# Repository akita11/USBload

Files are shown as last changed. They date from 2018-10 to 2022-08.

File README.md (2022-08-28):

# USBload
Dummy USB load

usbload

## これは何？
マイコンボードやLEDなどをモバイルバッテリーで駆動させるとき、急に電源が切れてしまうことはありませんか？
大抵のモバイルバッテリーは消費電流が弱い時にスリープするようになっています。

本モジュールをモバイルバッテリーに取り付けることで、定期的に負荷電流を流すことで、モバイルバッテリーをスリープさせないようにすることができます。

本モジュールは間欠で電流を流すことで、モバイルバッテリーの動作時間により影響を与えないようにしました。
また、端子を結線することで、消費電流値と電流の間欠期間を設定できます。
それにより、使用するモバイルバッテリーの挙動に合わせ、動作を調整することができます。

## USBloadとUSBload2の違い
モバイルバッテリーによってオス側が差し込めないものがあるとのご意見を戴き、USBload2はAタイプのオスコネクタをつけました。

※USBload2.1では使用するマイコンがSTC8G1K08に変更になっていますが、使い方は変更ありません。

usbload2

## 使い方
モバイルバッテリーに本モジュールのオス側を差し込み、メスコネクタに給電用USBケーブルを差し込むだけです。

※使用するモバイルバッテリーにあわせて、以下の「設定」を行う必要があります。

## 設定

### 電流間欠期間の設定方法

本モジュールを接続しない状態で、モバイルバッテリーをONにし、その後、自動的にスリープに入る（給電が止まる）までの時間を計測します。その時間に応じて、以下のとおり間欠期間を設定します。

間欠期間は、上記画像の赤色のA,Bパターンをショートすることで設定できます。

|A|B|間欠期間|補足|
|----|----|----|----|
|オープン|オープン|約24秒|30秒でスリープするモバイルバッテリー向け|
|ショート|オープン|約16秒|20秒でスリープするモバイルバッテリー向け|
|オープン|ショート|約12秒|15秒でスリープするモバイルバッテリー向け|
|ショート|ショート|約8秒|10秒でスリープするモバイルバッテリー向け|

### 消費電流値の設定方法
デフォルトで100mA流れるようになっており、上記画像の青色のパターンを1つショートするごとに電流値が100mA増えます。
多くのモバイルバッテリーは100mAのままでスリープを回避できるようですが、より多くの電流が必要なものもありますので、100mAのままではスリープを回避できない場合は、順に流す電流を増やしてください、

## その他
サイズ(USBload) : 18×12×10.5mm
サイズ(USBload2) : 35.6×17×11mm
モジュールの消費電流値 : 100mA～400mA  
モジュールの電流増減インターバル : 約10～30秒  

## （参考：自作する方向け）

USBload2.1（使用マイコン: STC8G1K08）のプログラムの書き込み方法はUSBload21_pgm.pdfを参照してください。

## 終わりに

USBloadの改良点がありましたら、ぜひIsuuesに書いてください。
こんな作品に作ったよ！という方は [#USBload](https://twitter.com/search?q=%23USBload&src=typed_query) を付けてSNSなどで公開してくださると嬉しいです。

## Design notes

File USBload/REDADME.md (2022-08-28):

# USBload/USBload2のプログラム書き込み方法

USBload/USBload2（使用マイコン：ATtiny10）の書き込みは[こちら](https://make.kosakalab.com/make/electronic-work/arduino-ide-dev/)を参照してください。

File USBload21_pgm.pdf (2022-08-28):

USBload2.1 の書き込み⽅法
2022/6/13 akita11

準備するもの
・ USB-シリアル変換器(FTDI-Basic 等。IO レベルが 5V のもの)
・ WindowsPC
・ 書き込みソフト：http://www.stcmcudata.com/ から「STC-ISP 软件 V6.89E 版」をダ ウンロードして展開
・ 書き込みケーブル（⾃作）：USBload2s と USB-シリアル変換器を以下のように接続す る。USB ケーブルを切断して A（平たい⽅）側から伸びるケーブルを、USB-シリアル 変換器につなぐピンヘッダにつなぐのが楽か？
Ø USB-A の p1(VDD)----USB-シリアル変換器の VDD(+5V)
Ø USB-A の p2(D-)---- USB-シリアル変換器の RXD
Ø USB-A の p3(D+)---- USB-シリアル変換器の TXD
Ø USB-A の p4(GND)---- USB-シリアル変換器の GND

書き込みソフト(STC-ISP)の初期設定
書き込みソフト STC-ISP を起動し、以下の 2 箇所を設定
・ MCU Type：”STC8G1K08A-8PIN”を選択
・ Scan Port：USB-シリアル変換器の COM ポート（たぶん⾃動で出てくる） ・ Open Code File：こちらの”USBlaod2S.bin”を指定 https://www.dropbox.com/s/422zqcihnlwcrv4/USBload2S.bin?dl=0
・ “H/W Option”内の下の⽅にある”Add a reset code in front of ID”をチェック

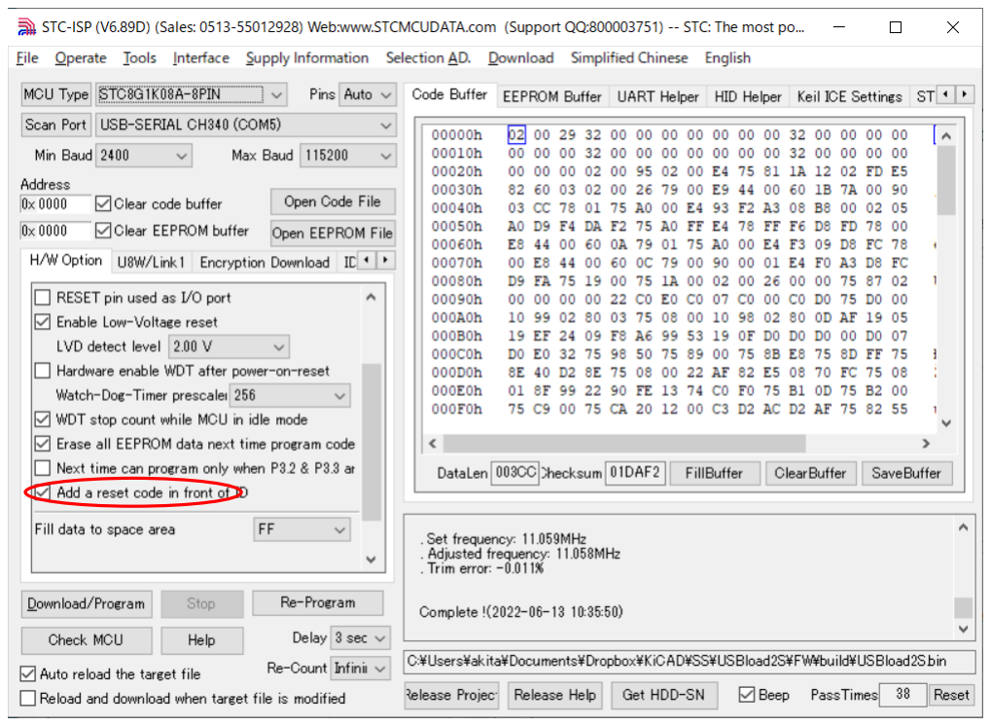
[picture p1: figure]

書き込み
1. STC-ISP で”Download/Program”ボタンを押す
2. USBload2S を書き込みケーブル（⾃作）に接続
3. 書き込みが始まり、すぐに終了するはず（STC-ISP の右下のエリア内に”Complete!”と 出ていれば OK

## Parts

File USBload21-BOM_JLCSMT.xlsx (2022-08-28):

Comment | Designator | Footprint | JLCPCB Part #（optional）
0.1uF | C1 | C0603 | C14663
USB-A recepctacle/TH | J3 |  | C2345
nMOS | Q1 | SOT23 | C20917
10k | R1 | R0603 | C25804
1.1k | R2 | R0603 | C22764
51 | R3,R4,R5,R6 | R0805 | C17732
STC8G1K08 | U1 | DFN8 | C915664

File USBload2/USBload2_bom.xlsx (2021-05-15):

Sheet: PCB Specification
Your PCB Specification
PCB Quantity | 100pcs
Layer | 2layer
PCB Thickness | 1.6mm
Dimensions | 20.6mm x 17.1mm
Castellated Hole | No
PCB Color | Black
Surface Finish | HASL Lead Free
Copper Weight | 1oz
Text Color | White
Different Design | 1
Please find more PCB information on our on-line PCB ordering Page
https://www.elecrow.com/pcb-manufacturing.html

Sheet: BOM
USBload2
# | Reference | QTY | Value | Package | Manufacturer Part number | Description | SMD | THT | Original | Elecrow PN | Note
1 | R1 | 1 | 10k | R0603 | P10KGCT-ND | Resistor | 2 |  | N
2 | R2-R4 | 4 | 51 | R0805 | RMCF0805JT51R0TR-ND | Resistor | 8 |  | N
2 | Q1 | 1 | IRLML6344 | SOT23-3 | IRLML6344TRPBFTR-ND | nMOS | 3 |  | Y
3 | U1 | 1 | ATTINY10 | SOT23-6 | ATTINY10-TSHRCT-ND | MCU | 6 |  | Y
4 | J2 | 1 |  |  | 102-3996-ND | USB connector |  | 6 | N
4 | J3 | 1 |  |  | 380-1412-ND | USB connector |  | 6 | N
5 | C1 | 1 | 0.1uF | C0603 |  | Capacitor | 2 |  | N
 |  |  |  |  |  | total： | 21 | 12
 | Declare：
 | 1、If the component should be original like Digi-key or Mouser，the component must have complete Manufacture part number

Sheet: Position File
Designator | Footprint | Center-X(mm) | Center-Y(mm) | Layer | Rotation
C1 | C_0603_1608Metric | 6.35 | 1.02 | BottomLayer | 180
Q1 | SOT-23 | 2.03 | 4.83 | BottomLayer | 0
R1 | R_0603_1608Metric | 2.03 | 2.29 | BottomLayer | 180
R2 | R_0805_2012Metric | 4.83 | 9.91 | BottomLayer | 270
R3 | R_0805_2012Metric | 12.19 | 9.91 | BottomLayer | 270
R4 | R_0805_2012Metric | 9.91 | 9.91 | BottomLayer | 270
R5 | R_0805_2012Metric | 7.87 | 9.91 | BottomLayer | 270
U1 | SOT-23-6 | 6.35 | 3.56 | BottomLayer | 180
J2 | USB Plug | 8.58 | 15.24 | TopLayer | 0
J3 | USB Recpt | 5.08 | 12.70 | TopLayer | 0

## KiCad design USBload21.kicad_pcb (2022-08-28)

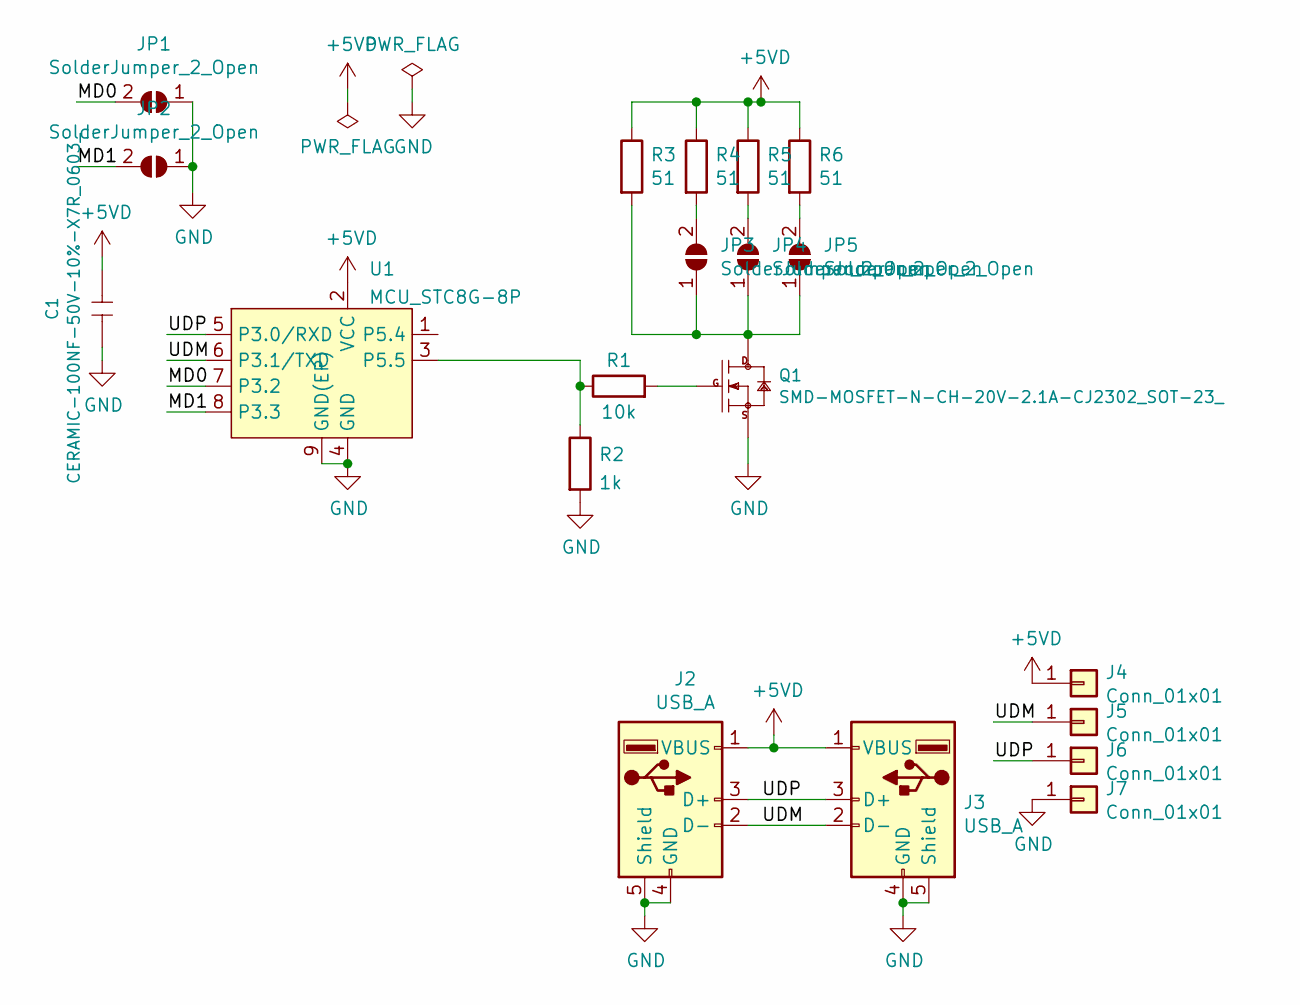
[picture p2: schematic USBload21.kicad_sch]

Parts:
C1: CERAMIC-100NF-50V-10%-X7R_0603_; C_0603_1608Metric; MPN CC0603KRX7R9BB104
J2: USB_A; USB-A_plug
J3: USB_A; USB_A_Stewart_SS-52100-001_Horizontal
J4, J5, J6, J7: Conn_01x01; Pad_SMD1.6mm
JP1, JP2, JP3, JP4, JP5: SolderJumper_2_Open; SolderJumper-2_P1.3mm_Open_RoundedPad1.0x1.5mm
Q1: SMD-MOSFET-N-CH-20V-2.1A-CJ2302_SOT-23_; SOT-23; MPN CJ2302
R1: 10k; R_0603_1608Metric
R2: 1k; R_0603_1608Metric
R3, R4, R5, R6: 51; R_0805_2012Metric
U1: MCU_STC8G-8P; DFN-8-1EP_3x3mm_P0.5mm_EP1.66x2.38mm

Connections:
+5VD: C1.2, J2.1 (VBUS), J3.1 (VBUS), J4.1, R3.1, R4.1, R5.1, R6.1, U1.2 (VCC)
/MD0: JP1.2 (B), U1.7 (P3.2)
/MD1: JP2.2 (B), U1.8 (P3.3)
/UDM: J2.2 (D-), J3.2 (D-), J5.1, U1.6 (P3.1/TXD)
/UDP: J2.3 (D+), J3.3 (D+), J6.1, U1.5 (P3.0/RXD)
GND: C1.1, J2.4 (GND), J2.5 (Shield), J3.4 (GND), J3.5 (Shield), J7.1, JP1.1 (A), JP2.1 (A), Q1.2 (S), R2.2, U1.4 (GND), U1.9 (GND(EP))
unnamed: JP3.1 (A), JP4.1 (A), JP5.1 (A), Q1.3 (D), R3.2
unnamed: JP3.2 (B), R4.2
unnamed: JP4.2 (B), R5.2
unnamed: JP5.2 (B), R6.2
unnamed: Q1.1 (G), R1.2
unnamed: R1.1, R2.1, U1.3 (P5.5)

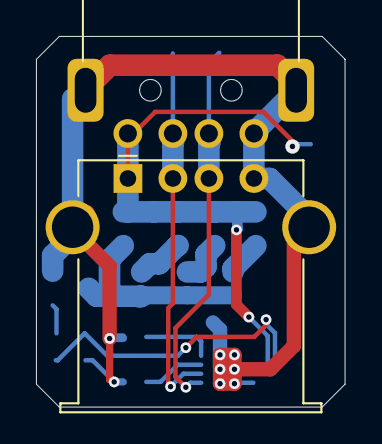
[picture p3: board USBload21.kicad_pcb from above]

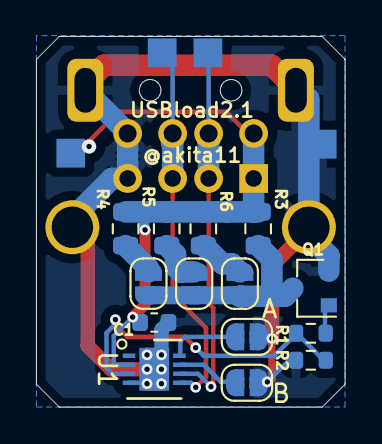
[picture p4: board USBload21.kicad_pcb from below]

Board: 2 copper layers, 17.1 x 20.6 mm, 20 parts (18 on the bottom side), 12 nets.

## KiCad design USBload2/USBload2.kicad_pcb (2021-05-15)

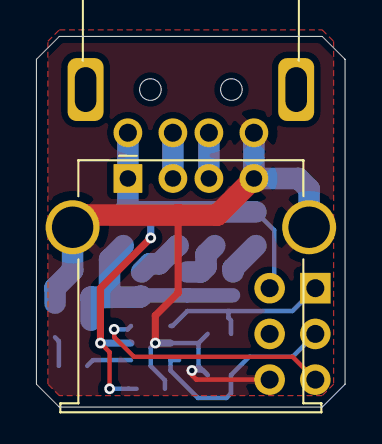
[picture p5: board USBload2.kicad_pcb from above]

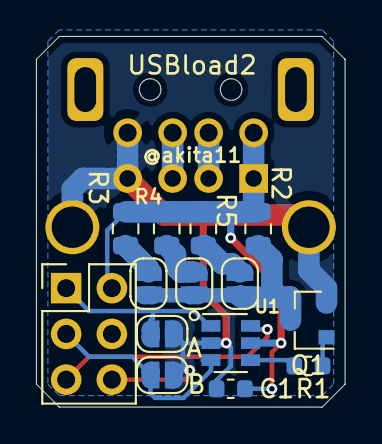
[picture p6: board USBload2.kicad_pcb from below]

Board: 2 copper layers, 17.1 x 20.6 mm, 16 parts (14 on the bottom side), 13 nets.

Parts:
C1: CERAMIC-100NF-50V-10%-X7R_0603_; C_0603_1608Metric
J1: AVR-ISP-6; PinHeader_2x03_P2.54mm_Vertical
J2: USB_A; USB-A_plug
J3: USB_A; USB_A_Stewart_SS-52100-001_Horizontal
JP1, JP2, JP3, JP4, JP5: SolderJumper_2_Open; SolderJumper-2_P1.3mm_Open_RoundedPad1.0x1.5mm
Q1: SMD-MOSFET-N-CH-20V-2.1A-CJ2302_SOT-23_; SOT-23
R1: SMD-RES-10K-1%-1_10W_0603_; R_0603_1608Metric
R2, R3, R4, R5: 51; R_0805_2012Metric
U1: ATtiny10-TS; SOT-23-6

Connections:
+5VD: C1.2, J1.2, J2.1, J3.1, R2.1, R3.1, R4.1, R5.1, U1.5
/PB0: J1.1, JP1.2, U1.1
/PB1: J1.3, JP2.2, U1.3
/PB3: J1.5, U1.6
GND: C1.1, J1.6, J2.4, J3.4, J3.5, JP1.1, JP2.1, Q1.2, U1.2
unnamed: J2.2, J3.2
unnamed: J2.3, J3.3
unnamed: JP3.1, JP4.1, JP5.1, Q1.3, R2.2
unnamed: JP3.2, R3.2
unnamed: JP4.2, R4.2
unnamed: JP5.2, R5.2
unnamed: Q1.1, R1.2
unnamed: R1.1, U1.4

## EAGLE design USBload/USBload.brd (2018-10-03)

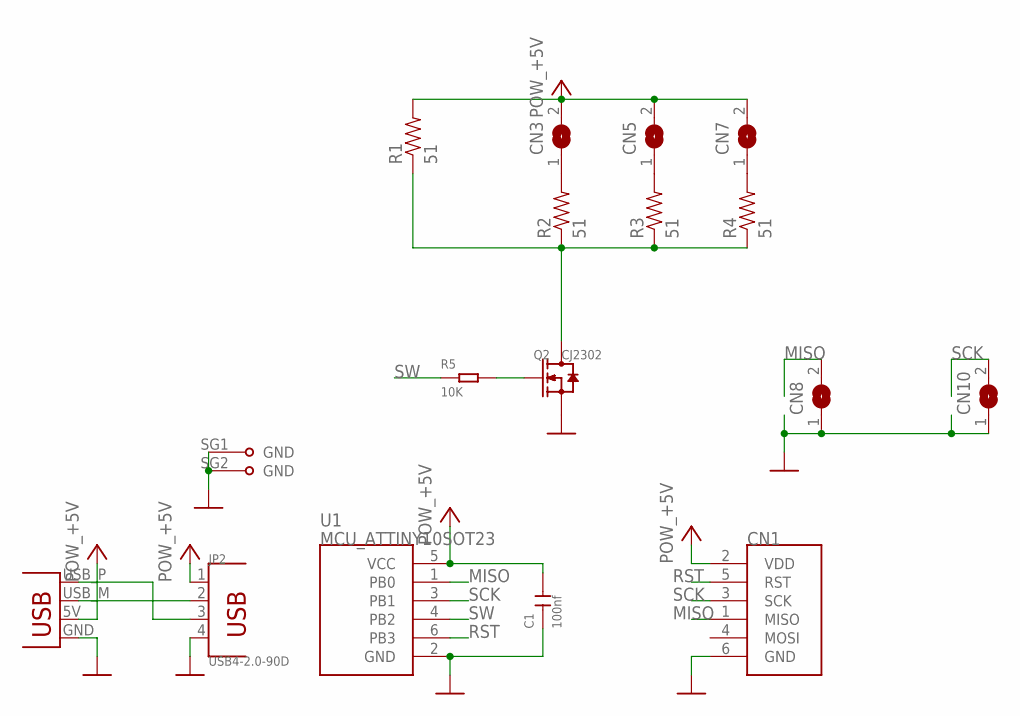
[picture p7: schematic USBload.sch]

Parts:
C1: 100nf; C0603
CN1: CON_AVRISPTH; 2X03R
CN3, CN5, CN7, CN8, CN10: JUMPER_SJ
JP1: CON_USBPCB; USB-A-PCB
JP2: USB4-2.0-90D; USB4+2P-2.0-90D
Q2: CJ2302; SOT-23
R1, R2, R3, R4: 51; 0805
R5: 10K; R0603
U1: MCU_ATTINY10SOT23; SOT23-6

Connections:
+5V: C1.2, CN1.2 (VDD), CN3.2, CN5.2, CN7.2, JP1.5V (VBUS), JP2.1, R1.2, U1.5 (VCC)
GND: C1.1, CN1.6 (GND), CN8.1, CN10.1, JP1.GND, JP2.4, JP2.SG1 (GND), JP2.SG2 (GND), Q2.2 (S), U1.2 (GND)
MISO: CN1.1 (MISO), CN8.2, U1.1 (PB0)
unnamed: JP1.USB_M (D-), JP2.2
unnamed: JP1.USB_P (D+), JP2.3
unnamed: CN5.1, R3.2
unnamed: CN3.1, R2.2
unnamed: CN7.1, R4.2
unnamed: Q2.1 (G), R5.2
unnamed: Q2.3 (D), R1.1, R2.1, R3.1, R4.1
RST: CN1.5 (RST), U1.6 (PB3)
SCK: CN1.3 (SCK), CN10.2, U1.3 (PB1)
SW: R5.1, U1.4 (PB2)

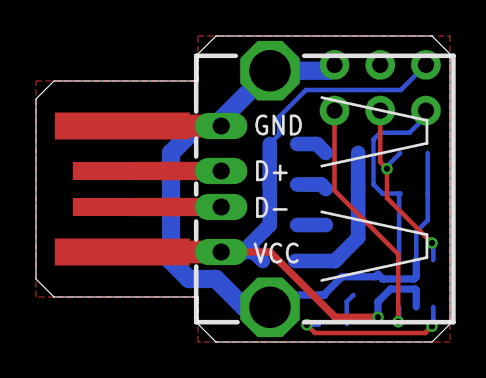
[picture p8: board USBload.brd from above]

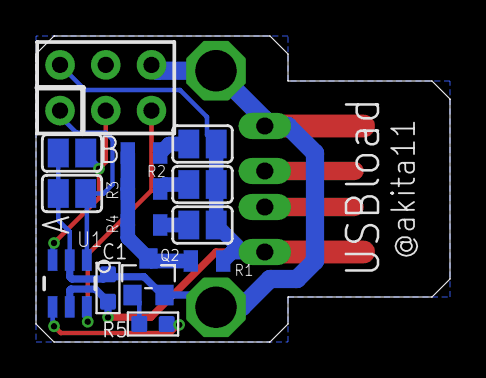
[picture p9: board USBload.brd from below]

Board: 2 copper layers, 23.0 x 17.0 mm, 16 parts (14 on the bottom side), 13 nets.

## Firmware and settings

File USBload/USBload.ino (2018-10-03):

   #include <avr/wdt.h>
#include <avr/sleep.h>

// Load active cycle [sec]
//#define T_CYCLE_AO_BO 28 // A=open,  B=open
//#define T_CYCLE_AC_BO 18 // A=close, B=open
//#define T_CYCLE_AO_BC 13 // A=open,  B=close
//#define T_CYCLE_AC_BC 8  // A=close, B=close --> 9.5sec

#define T_CYCLE_AO_BO 24 // A=open,  B=open  / 29s/1.2=24.2s / for 30s wake
#define T_CYCLE_AC_BO 15 // A=close, B=open  / 19s/1.2=15.8s / for 20s wake
#define T_CYCLE_AO_BC 11 // A=open,  B=close / 14s/1.2=11.7s / for 15s wake
#define T_CYCLE_AC_BC 7  // A=close, B=close / 9s/1.2=7.5s   / for 10s wake

#define LOAD 2
#define MD_A 0
#define MD_B 1

#define T_ON 1100 // 1.1sec

// ATtiny10 sleep (Power-down)
// SMCR = 0x40; // SM2:0=010
// SMCR |= 0x01; // SE(SleepEnable=1)
// SLEEP instruction

// Watchdog timer

uint8_t Tcycle;
uint8_t T = 0;

ISR(WDT_vect) {}

uint8_t i;

void setup() {
  pinMode(LOAD, OUTPUT);
  pinMode(MD_A, INPUT); // digitalWrite(MD_A, HIGH);
  pinMode(MD_B, INPUT); // digitalWrite(MD_B, HIGH);
  PUEB |= 0x03; // enable pull-ups
  if (digitalRead(MD_B) == 1) {
    if (digitalRead(MD_A) == 1) Tcycle = T_CYCLE_AO_BO;
    else Tcycle = T_CYCLE_AC_BO;
  }
  else {
    if (digitalRead(MD_A) == 1) Tcycle = T_CYCLE_AO_BC;
    else Tcycle = T_CYCLE_AC_BC;
  }
  // initial load for 1sec
  digitalWrite(LOAD, HIGH);
  for (i = 0; i < 1; i++) delay(T_ON);
  digitalWrite(LOAD, LOW);
  cli();
  SMCR |= (1 << SM1) | (1 << SE); // power down
  PRR |= (1 << PRADC); // disable ADC
  wdt_reset();
  //  WDTCSR =  0b01000000 | 0b00100001; // WDIE=1,  cycle=8s
  //  WDTCSR =  0b01000000 | 0b00000111; // WDIE=1,  cycle=2s
  WDTCSR =  0b01000000 | 0b00000110; // WDIE=1,  cycle=1s
  sei();
}

void loop() {
  set_sleep_mode(SLEEP_MODE_PWR_DOWN);
  sleep_enable();
  sleep_mode();
  // goes to sleep

  // wake from sleep
  sleep_disable();
  /*
    if (Tcycle == 0) { // continuous ON if Tcycle==0
      digitalWrite(LOAD, HIGH);
    }
    else {
    }
  */
  T++;
  if (T == Tcycle) {
    T = 0;
    digitalWrite(LOAD, HIGH);
    delay(T_ON);
    digitalWrite(LOAD, LOW);
  }
}

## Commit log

2018-10-03 add PCB data
    [USBload2_OPL.brd, USBload2_OPL.sch]
2018-10-03 add Arduino source
2018-10-09 Readmeの説明を追加
2018-10-09 設定方法を追記
2018-10-09 readmeを推敲
2020-07-08 USBload2に関する説明を追加
2021-05-15 ファイル名の整理とUSBload2のデータの追加
    [USBload.brd, USBload.sch, USBload2.kicad_pcb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]
2022-08-28 update for 2.1
    [USBload.brd, USBload.sch, USBload2.kicad_pcb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]
